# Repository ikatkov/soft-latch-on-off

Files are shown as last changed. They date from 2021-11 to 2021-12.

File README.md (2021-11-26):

# Software latch on-off switch

source https://www.eevblog.com/forum/beginners/push-button-power-circuit-for-arduino-trying-to-modify-it-for-12v-input/

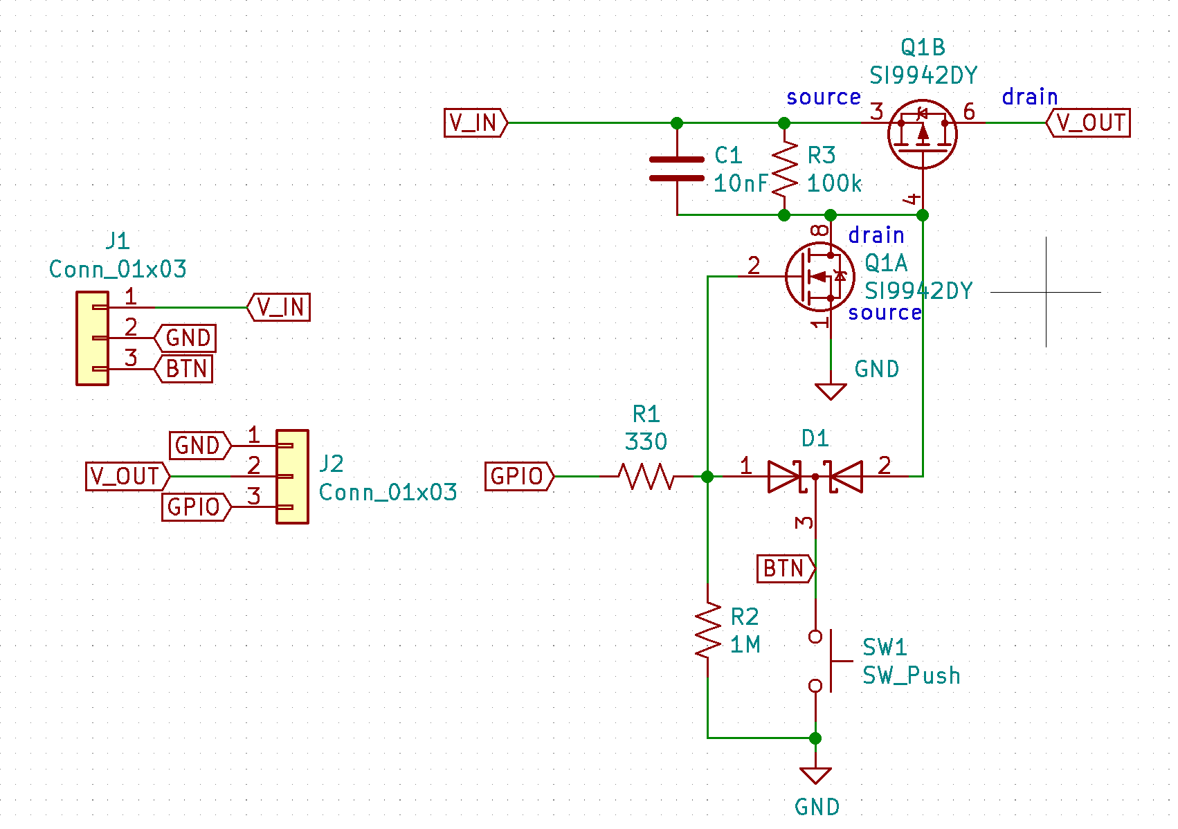
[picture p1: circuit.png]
 

The button turns on the P-MOSFET when pushed, and also pulls the Arduino GPIO low so button pushes can be detected. The diodes keep the GPIO level and PMOS gate level separate.   

To keep the power on after the user releases the button, enable the GPIO's weak pullup, which keeps the N-MOSFET gate high, which keeps the P-MOSFET on.  N.B. The N-MOSFET gate pulldown *MUST* be large compared to the Arduino internal weak pullup, which is max. 50K.

To turn the power off, the Arduino sets the GPIO to Output Low.  Power off will be delayed if the user is holding the button down.  Holding the button down wont force poweroff if the Arduino is crashed.

# Fabrication

See kicad files.

## BOM
| Id | Designator | Package | Designation | Value | 
| --- | --- | --- | --- |--- |
| 1 | D1 | SOT-23 | D_Schottky_x2_KCom_AAK | |
| 2 | R3 | R_Axial_DIN0204_L3.6mm_D1.6mm_P5.08mm_Horizontal |  | 100k | 
| 3 | R2 | R_Axial_DIN0204_L3.6mm_D1.6mm_P5.08mm_Horizontal |  | 1M | 
| 4 | R1 | R_Axial_DIN0204_L3.6mm_D1.6mm_P5.08mm_Horizontal |  | 330 | 
| 5 | Q1 | SOIC-8_3.9x4.9mm_P1.27mm | SI9942DY |  | 
| 6 | C1 | C_Disc_D4.7mm_W2.5mm_P5.00mm |  | 10nF | 
| 7 | J2,J1 | PinHeader_1x03_P2.54mm_Vertical | Conn_01x03 |  | 

## PCB

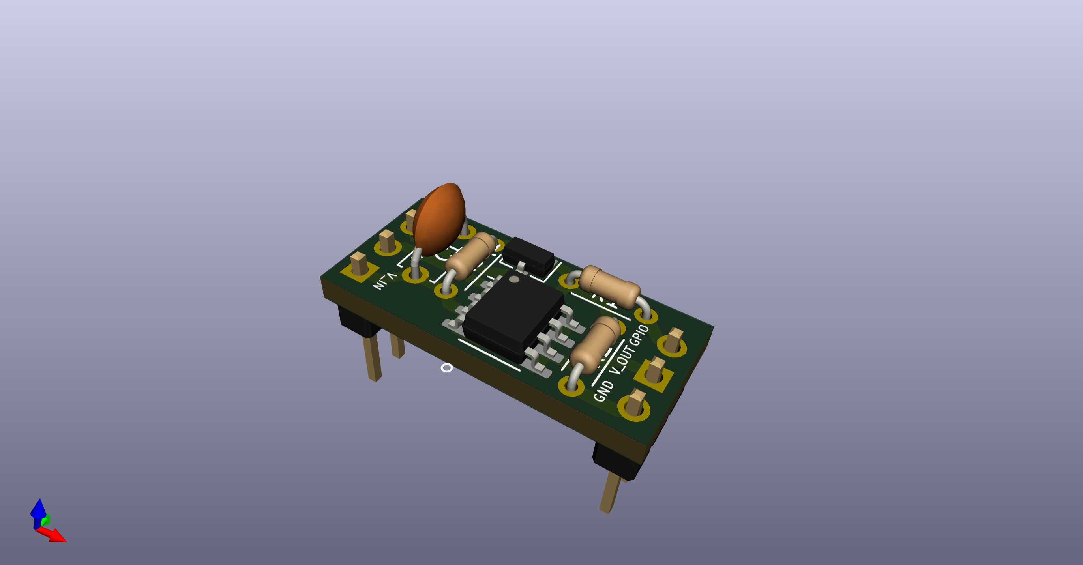
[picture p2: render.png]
 
 
 



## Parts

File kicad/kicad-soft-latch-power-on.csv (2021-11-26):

Id | Designator | Package | Quantity | Designation | Supplier and ref
1 | D1 | SOT-23 | 1 | D_Schottky_x2_KCom_AAK
2 | R3 | R_Axial_DIN0204_L3.6mm_D1.6mm_P5.08mm_Horizontal | 1 | 100k
3 | R2 | R_Axial_DIN0204_L3.6mm_D1.6mm_P5.08mm_Horizontal | 1 | 1M
4 | R1 | R_Axial_DIN0204_L3.6mm_D1.6mm_P5.08mm_Horizontal | 1 | 330
5 | Q1 | SOIC-8_3.9x4.9mm_P1.27mm | 1 | SI9942DY
6 | C1 | C_Disc_D4.7mm_W2.5mm_P5.00mm | 1 | 10nF
7 | J2,J1 | PinHeader_1x03_P2.54mm_Vertical | 2 | Conn_01x03

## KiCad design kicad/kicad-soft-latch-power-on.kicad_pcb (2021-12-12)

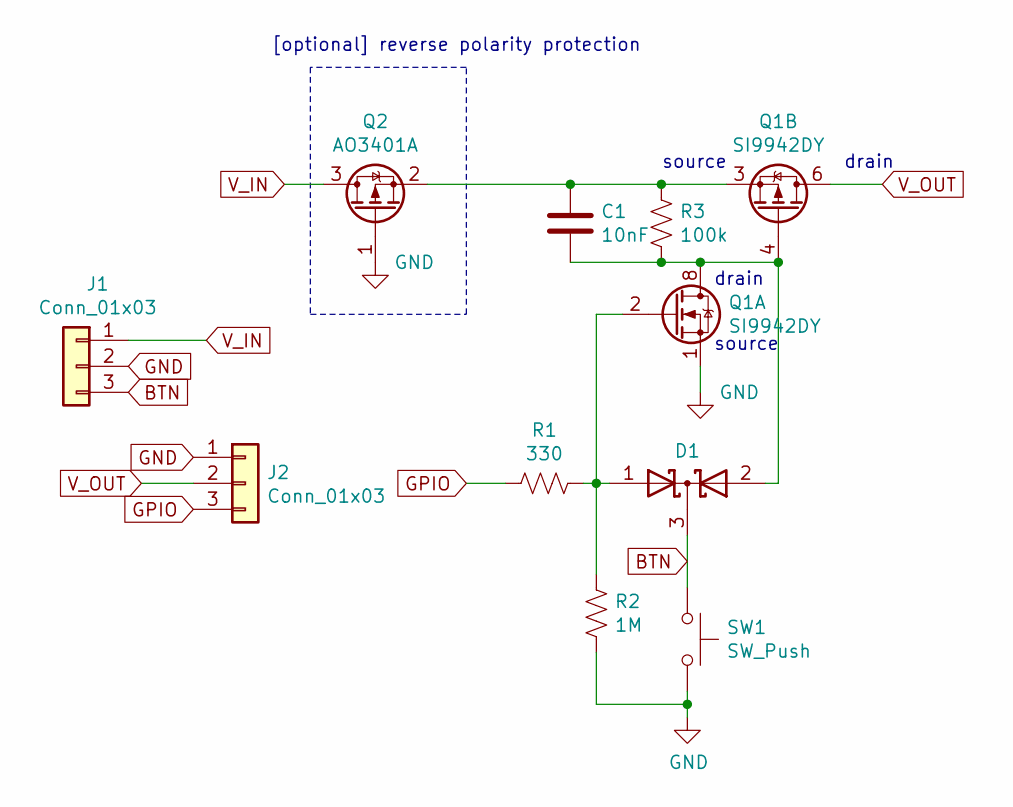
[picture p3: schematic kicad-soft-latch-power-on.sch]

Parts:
C1: 10nF; C_Disc_D4.7mm_W2.5mm_P5.00mm
D1: D_Schottky_x2_KCom_AAK; SOT-23
J1, J2: Conn_01x03; PinHeader_1x03_P2.54mm_Vertical
Q1: SI9942DY; SOIC-8_3.9x4.9mm_P1.27mm
Q2: AO3401A; SOT-23
R1: 330; R_Axial_DIN0204_L3.6mm_D1.6mm_P5.08mm_Horizontal
R2: 1M; R_Axial_DIN0204_L3.6mm_D1.6mm_P5.08mm_Horizontal
R3: 100k; R_Axial_DIN0204_L3.6mm_D1.6mm_P5.08mm_Horizontal
SW1: SW_Push; SW_PUSH_6mm

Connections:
BTN: D1.3 (K), J1.3, SW1.1
GND: J1.2, J2.1, Q1.1 (S), Q2.1 (G), R2.2, SW1.2
GPIO: J2.3, R1.2
unnamed: C1.1, Q1.3 (1), Q2.2 (S), R3.1
unnamed: C1.2, D1.2 (A), Q1.4 (G), Q1.7 (D), Q1.8 (D), R3.2
unnamed: D1.1 (A), Q1.2 (G), R1.1, R2.1
V_IN: J1.1, Q2.3 (D)
V_OUT: J2.2, Q1.5 (D), Q1.6 (D)

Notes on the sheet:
drain
source
[optional] reverse polarity protection

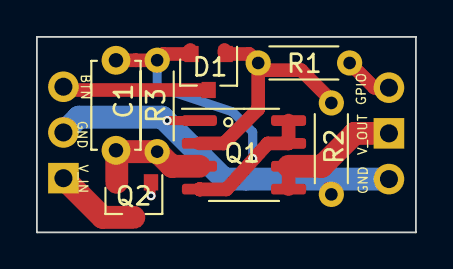
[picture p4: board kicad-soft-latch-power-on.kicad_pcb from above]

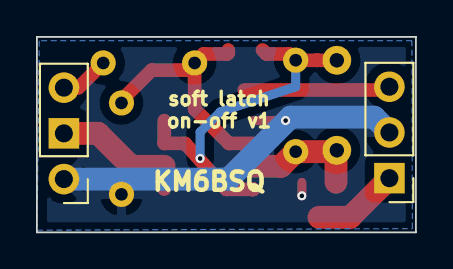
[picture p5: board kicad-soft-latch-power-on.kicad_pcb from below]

Board: 2 copper layers, 21.1 x 10.9 mm, 9 parts (2 on the bottom side), 8 nets.

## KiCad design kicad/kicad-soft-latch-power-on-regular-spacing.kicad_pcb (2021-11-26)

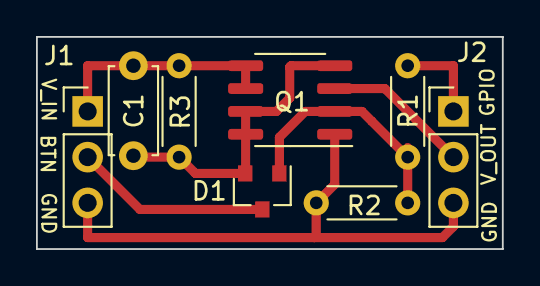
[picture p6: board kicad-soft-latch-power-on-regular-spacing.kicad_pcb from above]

Board: 2 copper layers, 25.9 x 11.8 mm, 8 parts (0 on the bottom side), 7 nets.

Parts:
C1: 10nF; C_Disc_D4.7mm_W2.5mm_P5.00mm
D1: D_Schottky_x2_KCom_AAK; SOT-23
J1, J2: Conn_01x03; PinHeader_1x03_P2.54mm_Vertical
Q1: SI9942DY; SOIC-8_3.9x4.9mm_P1.27mm
R1: 330; R_Axial_DIN0204_L3.6mm_D1.6mm_P5.08mm_Horizontal
R2: 1M; R_Axial_DIN0204_L3.6mm_D1.6mm_P5.08mm_Horizontal
R3: 100k; R_Axial_DIN0204_L3.6mm_D1.6mm_P5.08mm_Horizontal

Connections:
BTN: D1.3, J1.2
GND: J1.3, J2.3, Q1.1, R2.2
GPIO: J2.1, R1.2
unnamed: C1.2, D1.2, Q1.4, Q1.7, Q1.8, R3.2
unnamed: D1.1, Q1.2, R1.1, R2.1
V_IN: C1.1, J1.1, Q1.5, Q1.6, R3.1
V_OUT: J2.2, Q1.3

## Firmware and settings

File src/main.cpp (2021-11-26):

#include <Arduino.h>
#include <EasyButton.h>
static const byte CAL_BUTTON_PIN = 2;
static const byte LED_PIN = 13;

EasyButton calButton(CAL_BUTTON_PIN);
bool state;

void onPressedForDuration()
{
  Serial.println("onPressedForDuration");
  pinMode(CAL_BUTTON_PIN, OUTPUT);
  digitalWrite(CAL_BUTTON_PIN, LOW);
}

void onButtonPressed()
{
  Serial.println("onButtonPressed");
}

void setup()
{
  calButton.begin();
  calButton.onPressed(onButtonPressed);
  calButton.onPressedFor(2000, onPressedForDuration);
  pinMode(LED_PIN, OUTPUT);
  Serial.begin(9600);
  while (!Serial)
    delay(10);

  Serial.println("Setup");
}

void loop()
{
  calButton.read();
  state = !state;
  digitalWrite(13, state);
  delay(500);
}

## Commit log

2021-11-26 kicad sources
    [kicad-soft-latch-power-on-B_Mask.gbr, kicad-soft-latch-power-on-B_Paste.gbr, kicad-soft-latch-power-on-B_SilkS.gbr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]
2021-11-26 added render
    [kicad-soft-latch-power-on.kicad_pcb]
2021-11-26 updare schematic
    [kicad-soft-latch-power-on.sch]
2021-11-28 pcb update
    [kicad-soft-latch-power-on.sch]
2021-12-03 add reverse polarity protection
    [kicad-soft-latch-power-on.kicad_pcb, kicad-soft-latch-power-on.sch]
2021-12-12 final version with TH parts
    [kicad-soft-latch-power-on.kicad_pcb, kicad-soft-latch-power-on.sch]
